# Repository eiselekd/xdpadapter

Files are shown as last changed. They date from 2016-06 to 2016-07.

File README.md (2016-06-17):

# xdpadapter

Minnowboard.org adapter board for connecting to JTAG pins

## BOM

 * 4 bit 3.3V->1.8V level shifter http://www.ti.com/product/SN74LV4T125
   http://www.digikey.com/product-detail/en/texas-instruments/SN74LV4T125RGYR/296-40546-1-ND/5178423
   http://www.ti.com/lit/ds/symlink/sn74lv1t125.pdf
 * 1 bit 1.8V->3.3V level shifter http://www.ti.com/product/SN74LV1T125
   http://www.digikey.com/product-detail/en/texas-instruments/SN74LV1T125DCKR/296-37173-1-ND/4555590
   http://www.ti.com/lit/ds/symlink/sn74lv4t125.pdf
 * Connector Minnowboard: http://www.digikey.com/product-detail/en/3-5177986-2/A99215CT-ND/1894032
 * 20 pin ARM header: http://www.digikey.com/product-detail/en/samtec-inc/HTST-110-01-L-D/SAM8812-ND/2664195
 * Zener Diode 3.9V: http://www.digikey.com/product-detail/en/on-semiconductor/1SMA5915BT3G/1SMA5915BT3GOSCT-ND/1967012

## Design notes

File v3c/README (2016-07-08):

jtag> cable ft2232 pid=0x6010 vid=0x0403 interface=1

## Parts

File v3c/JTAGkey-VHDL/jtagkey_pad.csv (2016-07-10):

Release 8.1i - Fit P.20131013
Copyright(c) 1995-2003 Xilinx Inc. All rights reserved
 7-10-2016 10:08AM
NOTE: This file is designed to be imported into a spreadsheet program
such as Microsoft Excel for viewing, printing and sorting. The comma ','
character is used as the data field separator.
This file is also designed to support parsing.
Input file:  jtagkey.ngd
output file: jtagkey_pad.csv
Part type:   xc2c32a
Speed grade: -6
Package:     vq44
Pinout by Pin Number:
-----,-----,-----,-----,-----,-----,-----,-----,-----,-----,
Pin Number,Signal Name,Pin Usage,Pin Name,Direction,IO Standard,IO Bank Number,{blank},Slew Rate,Termination,{blank},Voltage,Constraint,
P1,FT_nSRST_OUT,I,I/O/GCK2,INPUT,LVCMOS18,1,,FAST,,,,
P2,FT_nTRST_OUT,I,I/O,INPUT,LVCMOS18,1,,FAST,,,,
P3,FT_RTCK,I,I/O,INPUT,LVCMOS18,1,,FAST,,,,
P4,GND,,GND,,,,,,,,,,
P5,FT_nSRST_IN,O,I/O,OUTPUT,LVCMOS18,1,,FAST,,,,
P6,FT_TARGET_PRESENT,O,I/O,OUTPUT,LVCMOS18,1,,FAST,,,,
P7,,VCCIO-1.8,VCCIO,,,1,,,,,,,
P8,FT_JTAG_OE,I,I/O,INPUT,LVCMOS18,1,,FAST,,,,
P9,TDI,,TDI,,,,,,,,,,
P10,TMS,,TMS,,,,,,,,,,
P11,TCK,,TCK,,,,,,,,,,
P12,FT_TMS,I,I/O,INPUT,LVCMOS18,1,,FAST,,,,
P13,FT_TDO,O,I/O,OUTPUT,LVCMOS18,1,,FAST,,,,
P14,FT_TDI,I,I/O,INPUT,LVCMOS18,1,,FAST,,,,
P15,,VCC,VCC,,,,,,,,,,
P16,FT_TCK,I,I/O,INPUT,LVCMOS18,1,,FAST,,,,
P17,GND,,GND,,,,,,,,,,
P18,TARGET_PRESENT,I,I,INPUT,LVCMOS18,2,,FAST,,,,
P19,TIE,,I/O,,,2,,,,,,,
P20,TIE,,I/O,,,2,,,,,,,
P21,TIE,,I/O,,,2,,,,,,,
P22,TIE,,I/O,,,2,,,,,,,
P23,TIE,,I/O,,,2,,,,,,,
P24,TDO,,TDO,,,,,,,,,,
P25,GND,,GND,,,,,,,,,,
P26,,VCCIO-1.8,VCCIO,,,2,,,,,,,
P27,TIE,,I/O,,,2,,,,,,,
P28,TIE,,I/O,,,2,,,,,,,
P29,DBGACK,I,I/O,INPUT,LVCMOS18,2,,FAST,,,,
P30,DBGRQ,O,I/O/GSR,OUTPUT,LVCMOS18,2,,FAST,,,,
P31,nSRST,I/O,I/O/GTS2,BIDIR,LVCMOS18,2,,FAST,,,,
P32,TDO,I,I/O/GTS3,INPUT,LVCMOS18,2,,FAST,,,,
P33,RTCK,O,I/O/GTS0,OUTPUT,LVCMOS18,2,,FAST,,,,
P34,TCK,O,I/O/GTS1,OUTPUT,LVCMOS18,2,,FAST,,,,
P35,,VCCAUX,VAUX,,,,,,,,,,
P36,TMS,O,I/O,OUTPUT,LVCMOS18,2,,FAST,,,,
P37,TDI,O,I/O,OUTPUT,LVCMOS18,2,,FAST,,,,
P38,nTRST,O,I/O,OUTPUT,LVCMOS18,2,,FAST,,,,
P39,TIE,,I/O,,,1,,,,,,,
P40,TIE,,I/O,,,1,,,,,,,
P41,FT_DBGACK,O,I/O,OUTPUT,LVCMOS18,1,,FAST,,,,
P42,FT_DBGRQ,I,I/O,INPUT,LVCMOS18,1,,FAST,,,,
P43,FT_nSRST_OE,I,I/O/GCK0,INPUT,LVCMOS18,1,,FAST,,,,
P44,FT_nTRST_OE,I,I/O/GCK1,INPUT,LVCMOS18,1,,FAST,,,,
To preserve the pinout above for future design iterations in
Project Navigator simply execute the (Lock Pins) process
located under the (Implement Design) process in a toolbox named
(Optional Implementation Tools) or invoke PIN2UCF from the
command line. The location constraints will be written into your
specified UCF file

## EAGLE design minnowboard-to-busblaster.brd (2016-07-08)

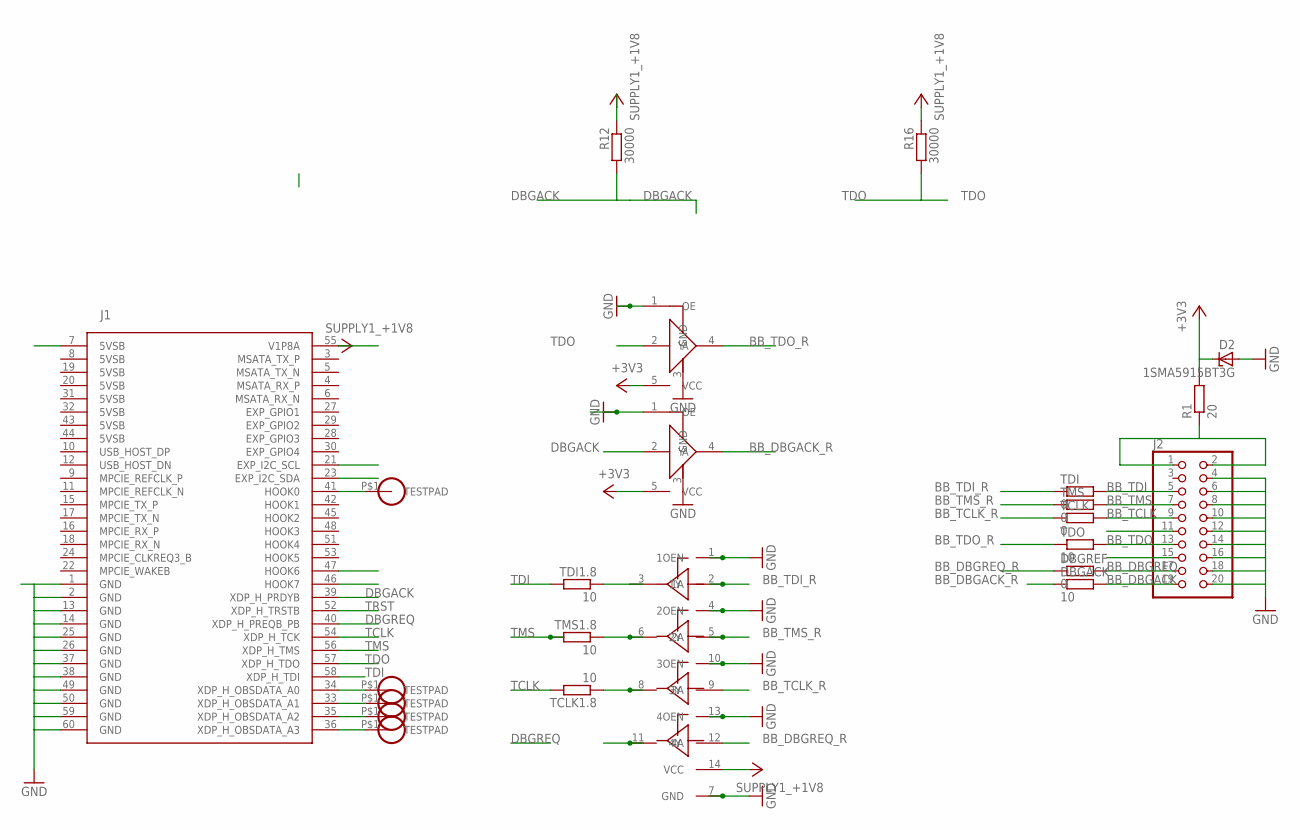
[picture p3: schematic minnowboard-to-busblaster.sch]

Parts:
A0, A1, A2, A3: TESTPAD
D2: 1SMA5915BT3G; DIODE_SMB
DBGACK: 10; R0805
DBGREF: 0; R0805
J1: CIRCUITCO_MINNOW2_HIGH_SPEED; CIRCUITCO_5177986-2
J2: LPC1768BOARD_PINHEAD_-_COPY_PINHD-2X10SHROUDED; LPC1768BOARD_PINHEAD_-_COPY_PINSHRD_PTH_2X10
R1: 20; R0805
R12, R16: 30000; R0805
TCLK: 0; R0805
TCLK1.8: 10; R0805
TDI: 0; R0805
TDI1.8: 10; R0805
TDO: 10; R0805
TMS: 0; R0805
TMS1.8: 10; R0805
U1: SN74LV4T125; PVQFN-N14
U2, U3: SN74LV1T125; SC70-5
U$1: TESTPAD

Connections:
+1V8: J1.55 (V1P8A), R12.1, R16.1, U1.14 (VCC)
+3V3: D2.C, R1.2, U2.5 (VCC), U3.5 (VCC)
BB_DBGACK: DBGACK.2, J2.19
BB_DBGACK_R: DBGACK.1, U2.4 (Y)
BB_DBGREQ: DBGREF.2, J2.17
BB_DBGREQ_R: DBGREF.1, U1.12 (4A)
BB_TCLK: J2.9, TCLK.2
BB_TCLK_R: TCLK.1, U1.9 (3A)
BB_TDI: J2.5, TDI.2
BB_TDI_R: TDI.1, U1.2 (1A)
BB_TDO: J2.13, TDO.2
BB_TDO_R: TDO.1, U3.4 (Y)
BB_TMS: J2.7, TMS.2
BB_TMS_R: TMS.1, U1.5 (2A)
DBGACK: J1.39 (XDP_H_PRDYB), R12.2, U2.2 (A)
DBGREQ: J1.40 (XDP_H_PREQB_PB)
GND: D2.A, J1.1 (GND), J1.2 (GND), J1.13 (GND), J1.14 (GND), J1.25 (GND), J1.26 (GND), J1.37 (GND), J1.38 (GND), J1.49 (GND), J1.50 (GND), J1.59 (GND), J1.60 (GND), J2.4, J2.18, J2.20, U1.1 (1OEN), U1.4 (2OEN), U1.7 (GND), U1.10 (3OEN), U1.13 (4OEN), U2.1 (OE), U2.3 (GND), U3.1 (OE), U3.3 (GND)
unnamed: J2.1, J2.2, R1.1
unnamed: TMS1.8.1, U1.6 (2Y)
unnamed: TDI1.8.1, U1.3 (1Y)
unnamed: TCLK1.8.1, U1.8 (3Y)
unnamed: A2.P$1, J1.35 (XDP_H_OBSDATA_A2)
unnamed: A0.P$1, J1.34 (XDP_H_OBSDATA_A0)
unnamed: A1.P$1, J1.33 (XDP_H_OBSDATA_A1)
unnamed: A3.P$1, J1.36 (XDP_H_OBSDATA_A3)
RMRST: J1.41 (HOOK0), U$1.P$1
TCLK: J1.54 (XDP_H_TCK), TCLK1.8.2
TDI: J1.58 (XDP_H_TDI), TDI1.8.2
TDO: J1.57 (XDP_H_TDO), R16.2, U3.2 (A)
TMS: J1.56 (XDP_H_TMS), TMS1.8.2
TRST: J1.52 (XDP_H_TRSTB)

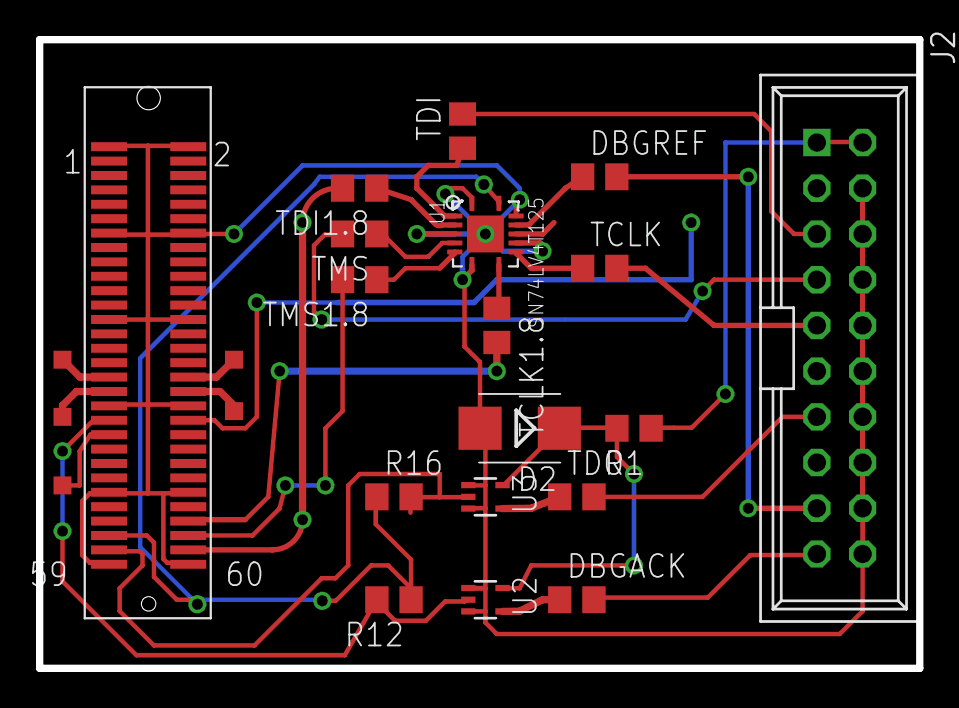
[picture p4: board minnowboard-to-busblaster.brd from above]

Board: 2 copper layers, 48.9 x 34.9 mm, 23 parts (0 on the bottom side), 29 nets.
